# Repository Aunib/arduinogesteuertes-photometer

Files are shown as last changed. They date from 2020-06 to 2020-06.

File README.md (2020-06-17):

# arduinogesteuertes-photometer
Ein arduinogesteuertes Photometer für den Gebrauch an Schulen, entwickelt im Rahmen der Vorbereitung auf meine MSA-Präsentationsprüfung im Schuljahr 2019/20. Die Idee stammt von der Technologiestiftung Berlin.
Textinhalte, Code und Fotos dieses Werkes können genutzt und geteilt werden unter einer Creative Commons NonCommercial-ShareAlike 4.0 International Licensze. (CC BY-NC-SA 4.0)
Als Namensnennung ist anzugeben: Simon Steinberg, 2020.

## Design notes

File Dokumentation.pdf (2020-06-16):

# Bauanleitung für ein „arduinogesteuertes Photometer für den Gebrauch an Schulen“

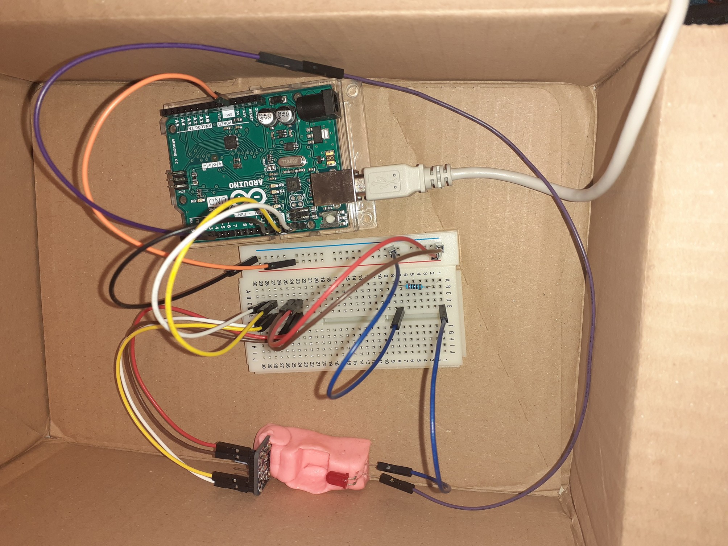
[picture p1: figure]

## Ein MSA-Projekt von Simon Steinberg an der Comenius-Schule Berlin im Auftrag der Technologiestiftung Berlin

## Schuljahr 2019/20

## Inhaltsverzeichnis

## Einkaufsliste

- 1 Arduino UNO
- LED beliebiger Farbe (je nach zu messenden Substanzen, wechselbar)
- 1 Breadboard
- USB-Kabel A auf B
- Lichtsensor: Adafruit TSL 2561
- 8 Jumperkabel male/male
- 6 Jumperkabel male/female
- 1 Widerstand (Stärke hängt von der LED ab, ich verwendete 220 Ω))
- Küvetten zum testen
- Fimo
- Pappkarton o.ä.
- Laptop/stationärer PC mit USB-Anschluss (wird nicht fest verbaut, ist aber zum Programmieren und für die Bedienung nötig)

## Werkzeug

- Backofen
- evtl. Lötkolben (je nach Ausführung des TSL 2561)

## Schaltplan

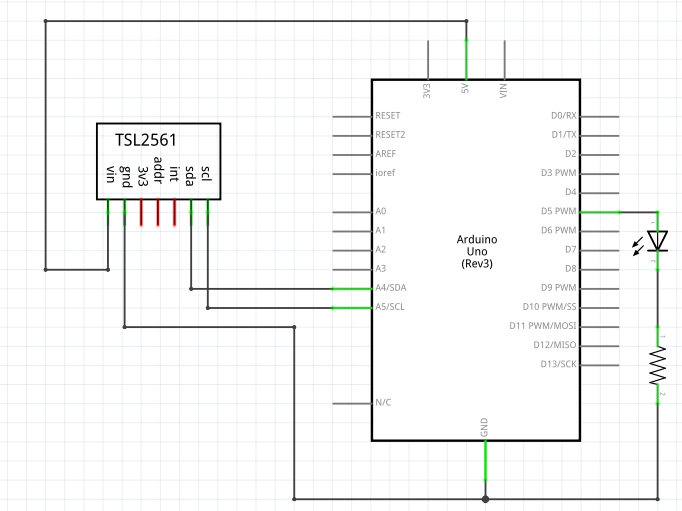
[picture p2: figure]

## Zusammenbau

Der Zusammenbau der Schaltung gestaltet sich relativ einfach:

1. Man nimmt die Bauteile und steckt sie anhand des Schaltplans auf das Breadboard. Dabei ist zu beachten, dass man den Lichtsensor und die LED über male/female Kabel so anschließt, dass man sie im Karton bewegen kann (Damit ist gemeint, dass diese nicht fest auf das Breadboard gesteckt werden. (Siehe Titelbild)).
2. Danach muss man das „Fimo“ in Form bringen
(siehe Bild), welches die Komponenten so
ausrichtet, dass eine Messung möglich wird und gleichzeitig als Halterung für die Messküvette dient.
3. Nachdem man das „Fimo“ geformt hat muss es bei 130 °C für 15 min. in den Ofen.
4. Danach kann man die vorher vorbereiteten Kabel an die LED und den Lichtsensor anschließen.

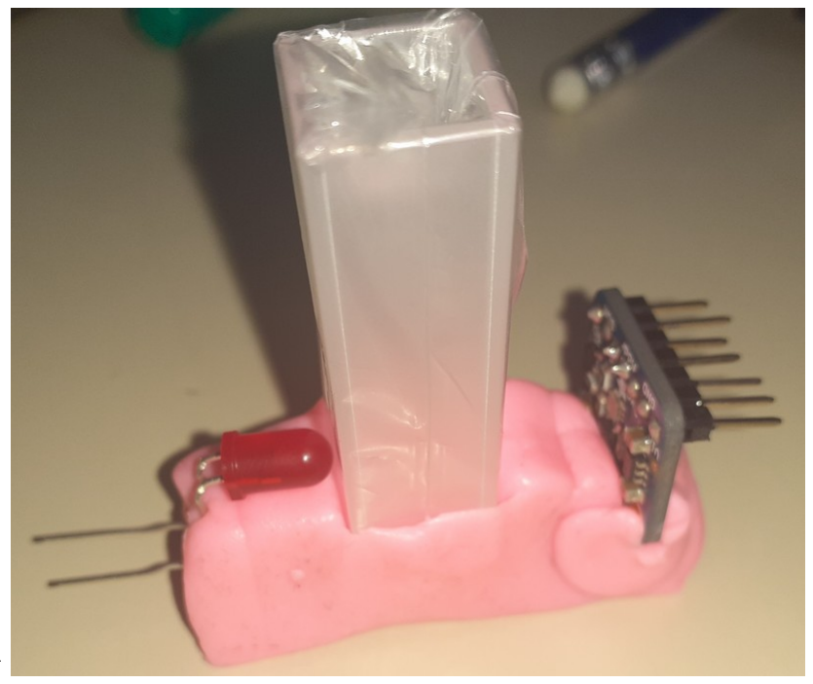
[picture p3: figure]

5. Der USB-Anschluss des Arduino wird nun mit dem USB-Kabel verbunden, dessen anderes Ende im
PC/Laptop steckt.
6. Nun kann man den Arduino mit der korrekten
Software versorgen. Dies wird mit der Arduino-IDE (arduino.cc) erledigt. Dabei benötigt eine nachzuinstallierende Bibliothek namens „Adafruit TSL2561“.
7. Bevor der Code hochgeladen wird, muss man in der Arduino-IDE den seriellen Port einstellen. Dies tut man, indem man auf Werkzeuge => Port geht und dort den Punkt auswählt, hinter dem „(Arduino UNO)“ steht. Dieser Schritt muss jedes mal, wenn man auf den Arduino zugreifen möchte, wiederholt werden. (Also auch vor der Bedienung mit dem seriellen Monitor)
8. Nun kann man den Code laden und auf den Arduino hochladen.
9. Um das Photometer zu bedienen wird der Serielle Monitor (Werkzeuge => Serieller Monitor) genutzt. Die dortige Bedienoberfläche ist relativ selbsterklärend.

Hier sieht man das geformte „Fimo“ mit den Teilen, welche als Formhilfe verwendet werden können.

## Code&Dokumentation

## Software

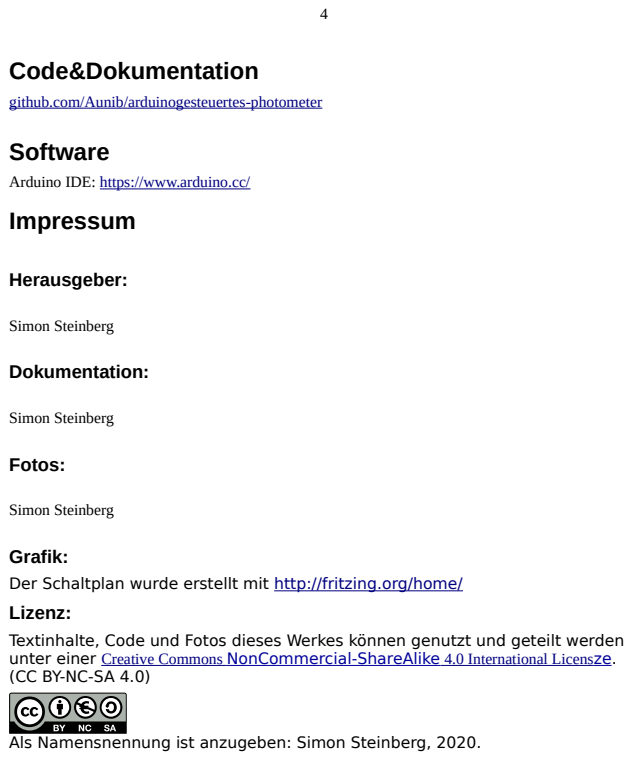
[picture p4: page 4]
Herausgeber:; Simon Steinberg; Dokumentation:; Fotos:

github.com/Aunib/arduinogesteuertes-photometer

Arduino IDE: https://www.arduino.cc/
Impressum

Grafik:
Der Schaltplan wurde erstellt mit http://fritzing.org/home/
Lizenz:
Textinhalte, Code und Fotos dieses Werkes können genutzt und geteilt werden
unter einer Creative Commons (http://creativecommons.org/licenses/by-nc-sa/4.0/) NonCommercial-ShareAlike 4.0 International Licens (http://creativecommons.org/licenses/by-nc-sa/4.0/) z (http://creativecommons.org/licenses/by-nc-sa/4.0/) e. (http://creativecommons.org/licenses/by-nc-sa/4.0/)

Als Namensnennung ist anzugeben: Simon Steinberg, 2020.

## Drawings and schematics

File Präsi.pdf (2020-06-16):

# Arduinogesteuertes Photometer

Entwickelt für den Gebrauch in Schulen

Simon Steinberg

## Inhaltsverzeichnis

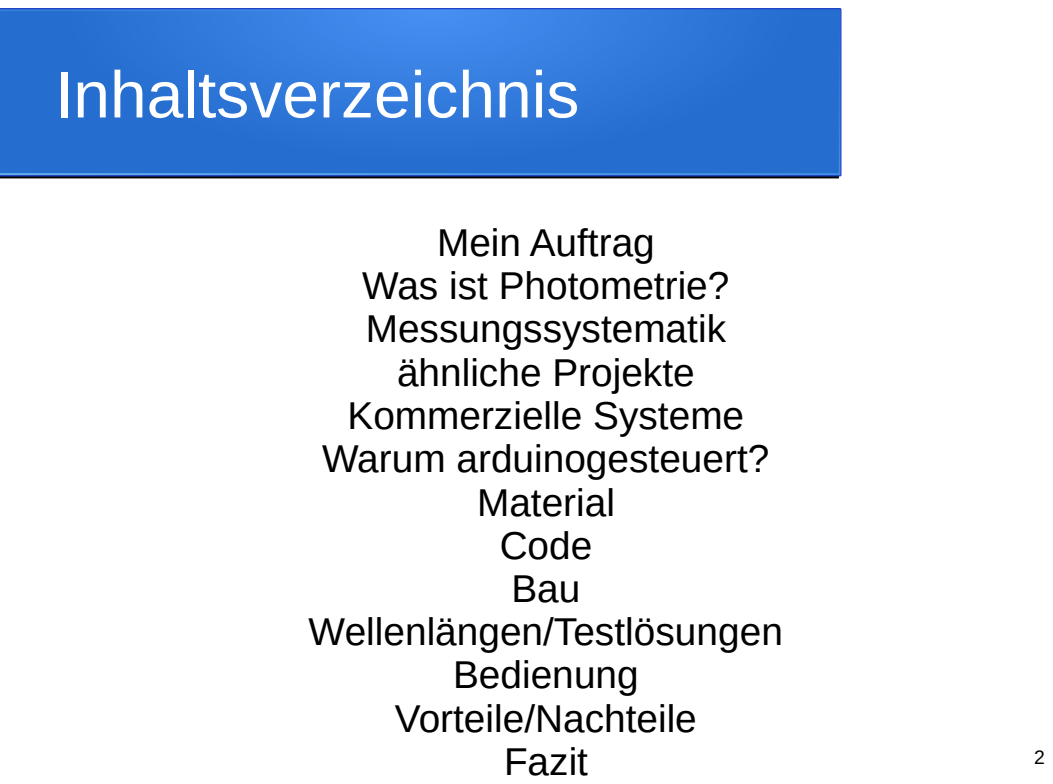
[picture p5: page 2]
Material Code Bau Wellenlängen/Testlösungen Bedienung Vorteile/Nachteile Fazit

Mein Auftrag
Was ist Photometrie?
Messungssystematik
ähnliche Projekte
Kommerzielle Systeme
Warum arduinogesteuert?

## Mein Auftrag

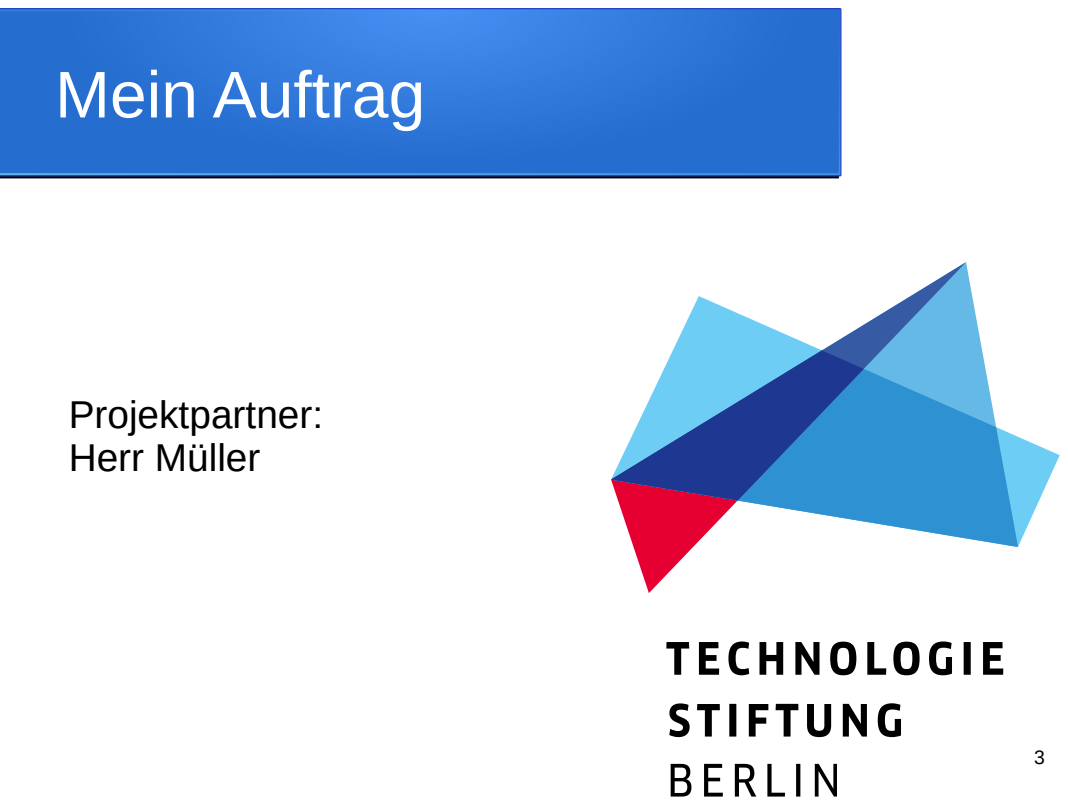
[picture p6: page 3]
Projektpartner: Herr Müller

## Was ist Photometrie?

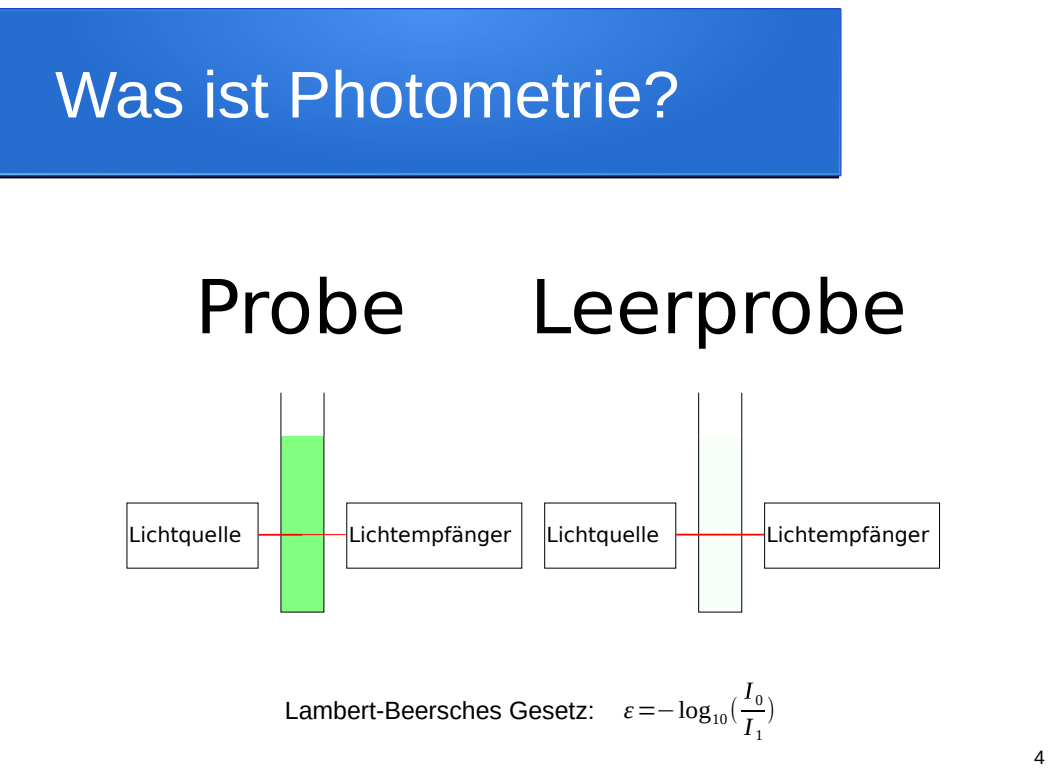
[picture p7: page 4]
Lichtquelle; Lichtempfänger; Probe; Leerprobe

Lambert-Beersches Gesetz: ε=−log10 (

## Messungssystematik

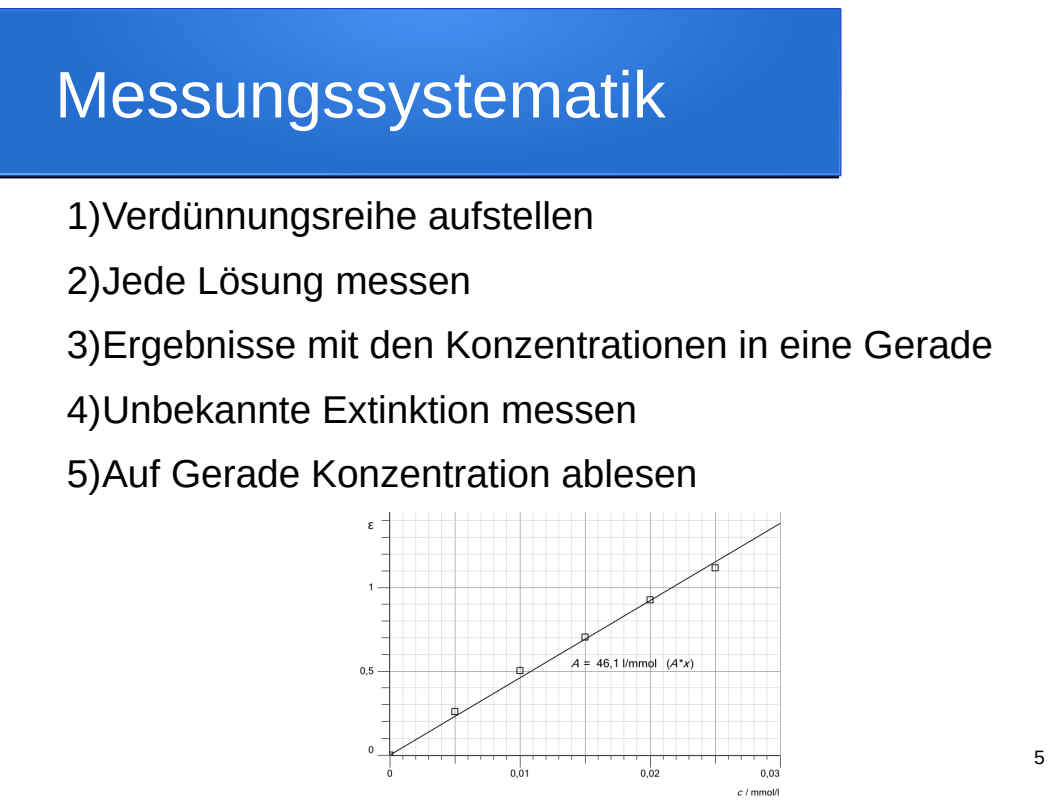
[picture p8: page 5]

1)Verdünnungsreihe aufstellen
2)Jede Lösung messen
3)Ergebnisse mit den Konzentrationen in eine Gerade
4)Unbekannte Extinktion messen
5)Auf Gerade Konzentration ablesen

## Was gibt es noch an Projekten?

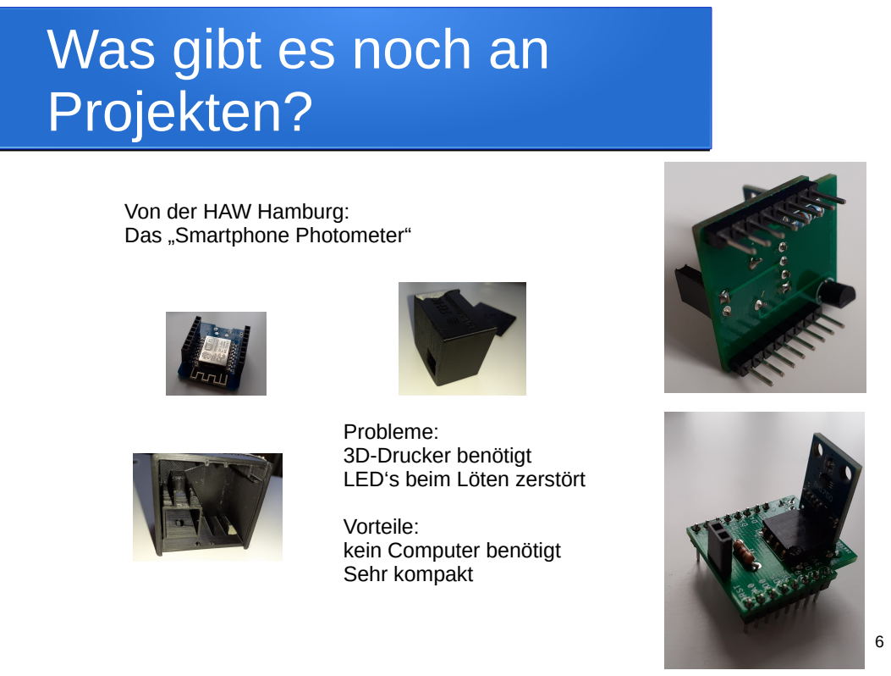
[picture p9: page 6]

Von der HAW Hamburg:
Das „Smartphone Photometer“

Probleme:
3D-Drucker benötigt
LED‘s beim Löten zerstört

Vorteile:
kein Computer benötigt
Sehr kompakt

## Kommerzielle Lösungen

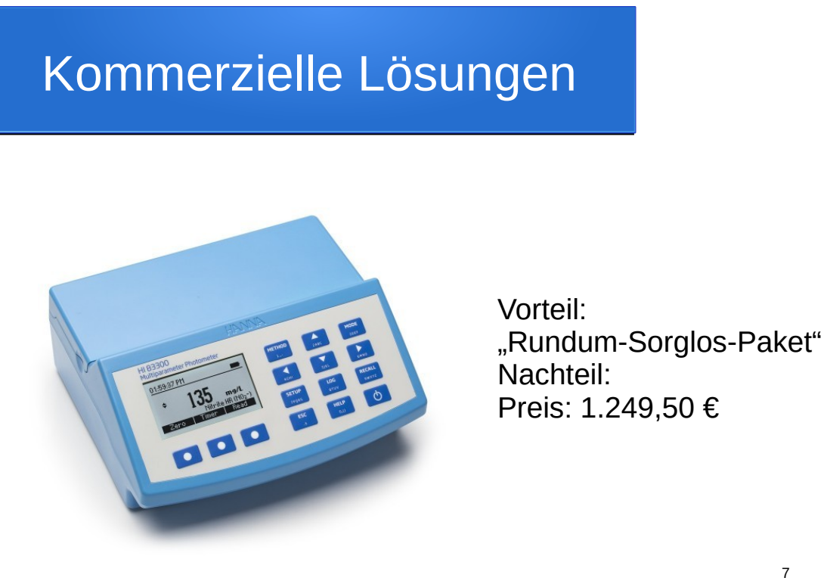
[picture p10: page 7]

Vorteil:
„Rundum-Sorglos-Paket“
Nachteil:
Preis: 1.249,50 €

## Warum Arduinogesteuert?

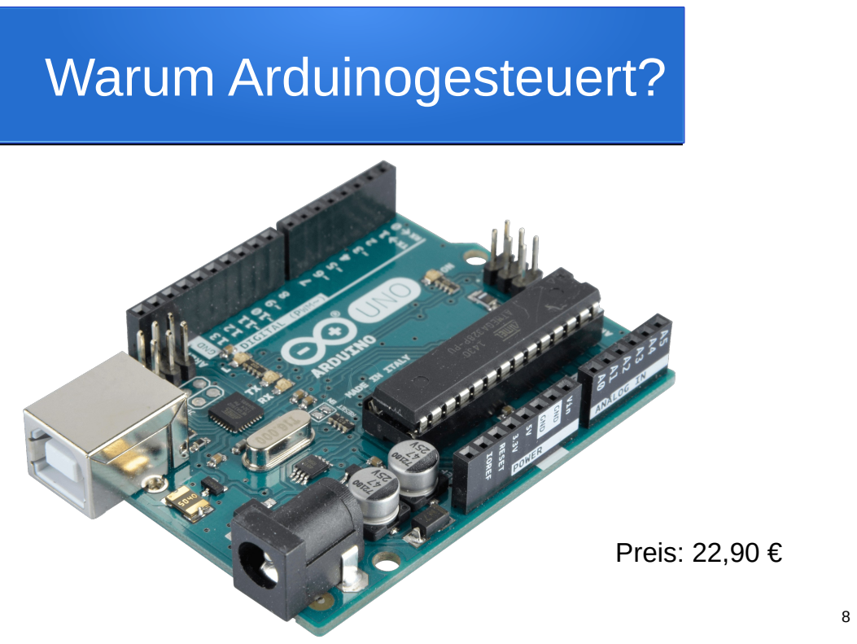
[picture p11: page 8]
Preis: 22,90 €

## Material

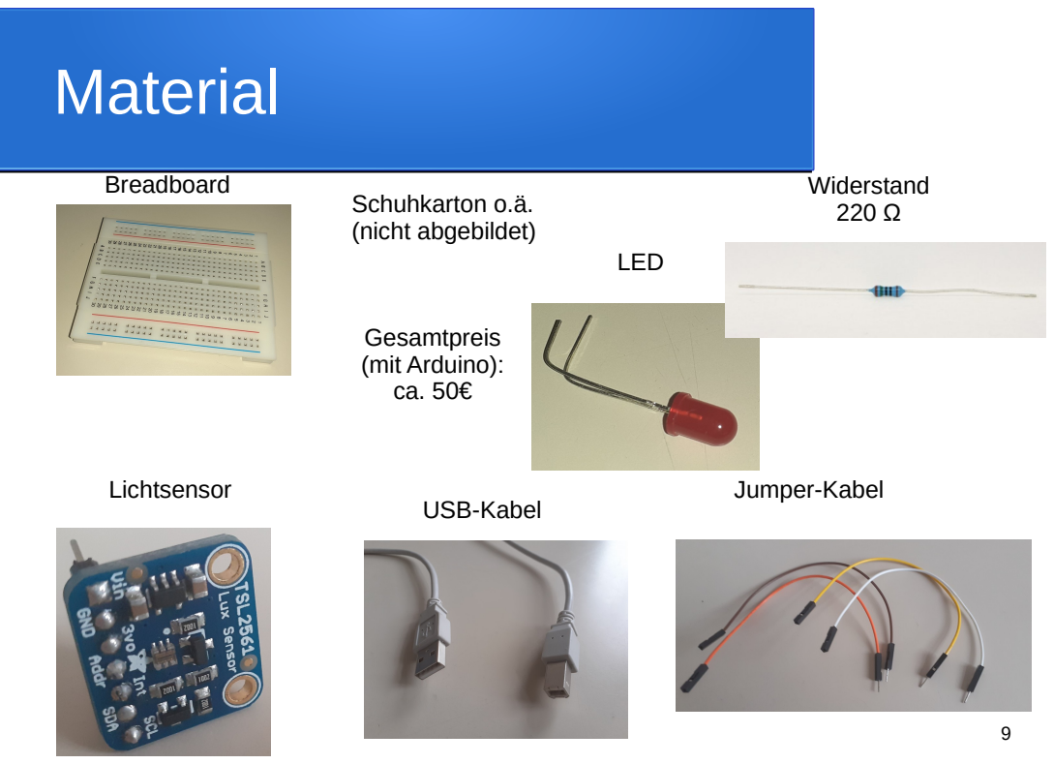
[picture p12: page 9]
Breadboard; LED; Lichtsensor; Jumper-Kabel; USB-Kabel; Gesamtpreis (mit Arduino): ca. 50€; Schuhkarton o.ä. (nicht abgebildet); Widerstand 220 Ω

## Code

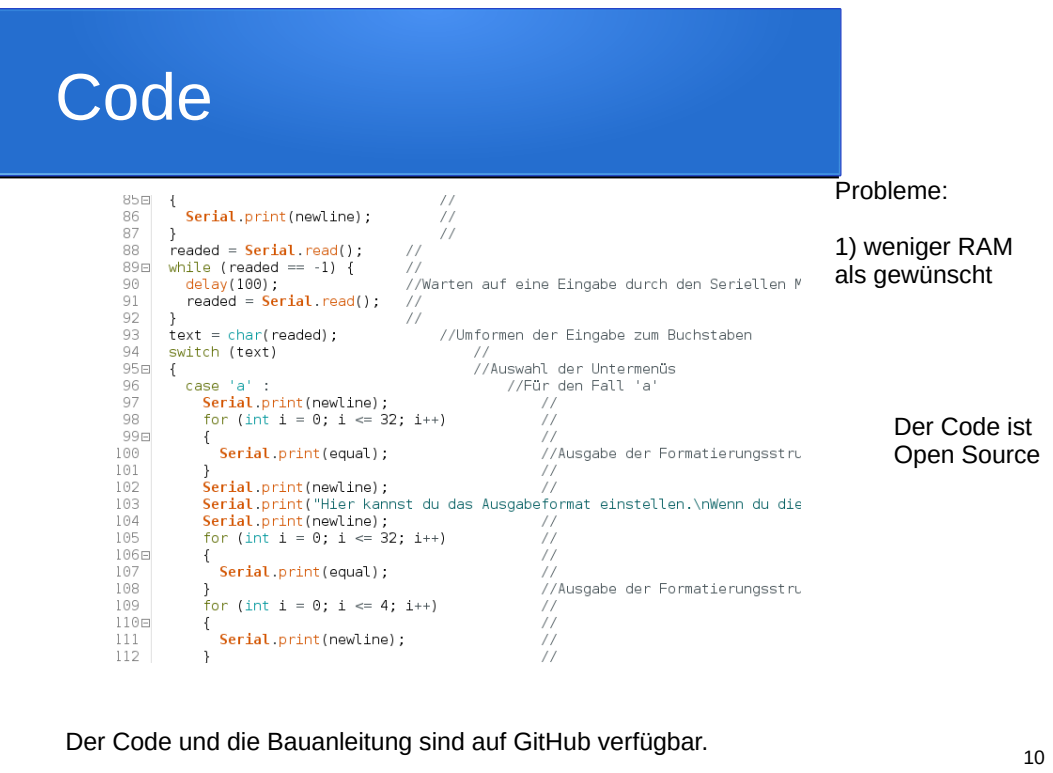
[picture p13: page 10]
Probleme:; 1) weniger RAM als gewünscht

Der Code ist
Open Source

Der Code und die Bauanleitung sind auf GitHub verfügbar.

## Bau

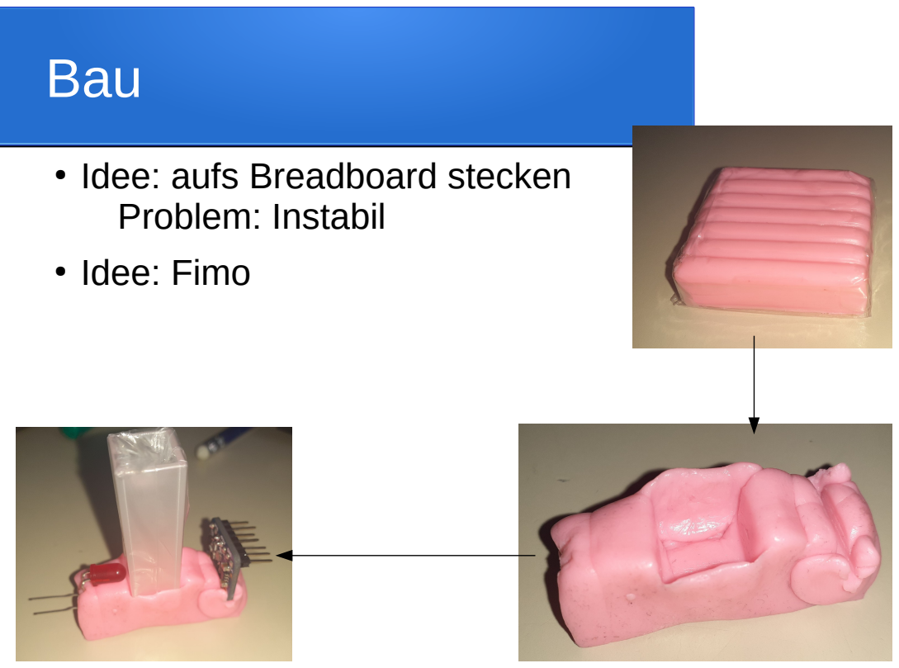
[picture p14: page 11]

● Idee: aufs Breadboard stecken
Problem: Instabil
● Idee: Fimo

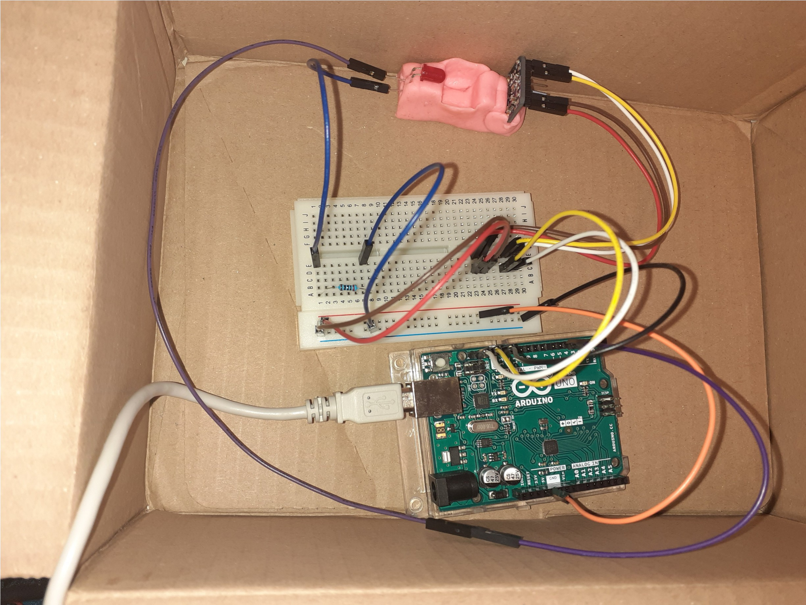
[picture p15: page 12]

## Wellenlängen/ Testlösungen

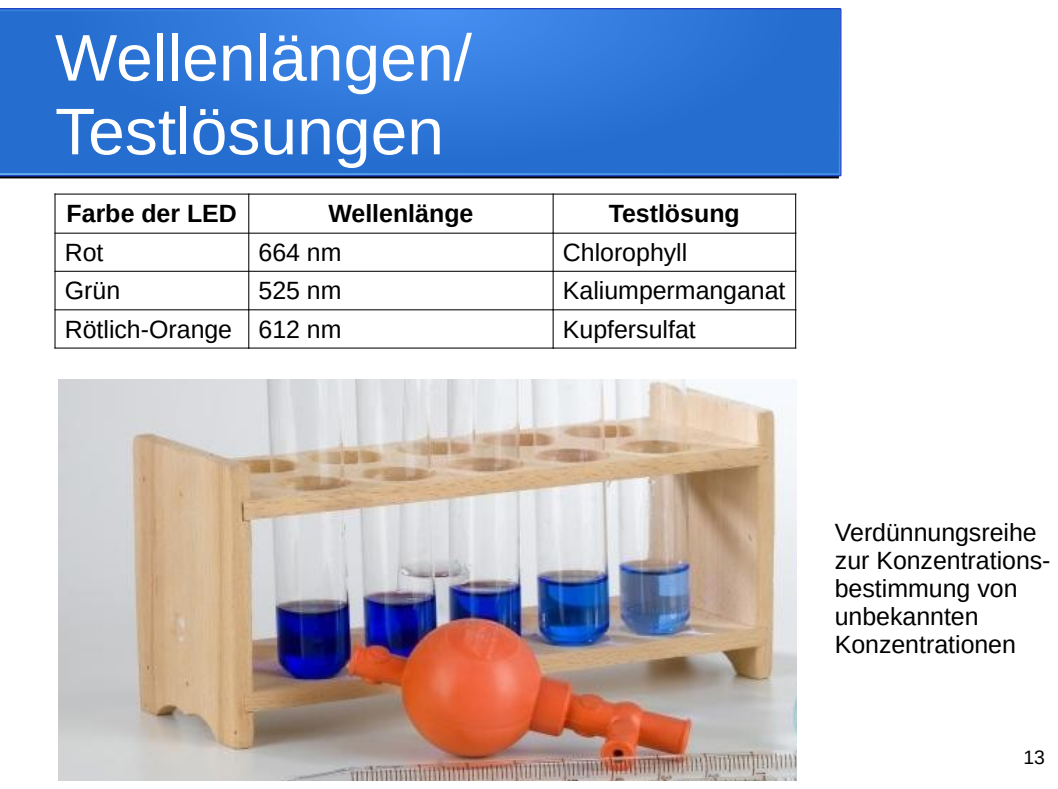
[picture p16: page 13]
Verdünnungsreihe zur Konzentrations- bestimmung von unbekannten Konzentrationen

Farbe der LED | Wellenlänge | Testlösung
Rot | 664 nm | Chlorophyll
Grün | 525 nm | Kaliumpermanganat
Rötlich-Orange | 612 nm | Kupfersulfat

## Bedienung


Mit dem seriellen Monitor

## Vorteile/Nachteile meiner Lösung

Vorteile; Nachteile

● mehrere zeitgleiche Experimente
möglich
● Erfahrungen in
IT/Elektronik beim Bau
● relativ preisgünstig

● Pro Photometer ein Laptop oder
PC benötigt
● verschiedene Zwischenergebnisse
bei verschiedenen Aufbauten?

## Fazit


● Auftrag von Herr Müller erfüllt
● Code geschrieben
● Prototyp entwickelt
● An Schulen einsetzbar

# Danke für Ihre Aufmerksamkeit

## Quellen


● https://hannainst.de/media/image/48/a6/b8/
hi83300_600x600.jpg (https://hannainst.de/media/image/48/a6/b8/hi83300_600x600.jpg)
● https://cdn-reichelt.de/bilder/web/xxl_ws/A3
00/ARDUINO_UNO_DIP_01.png (https://cdn-reichelt.de/bilder/web/xxl_ws/A300/ARDUINO_UNO_DIP_01.png)
● https://www.technologiestiftung-berlin.de/typ
o3conf/ext/ccdm_tsbtemplate/Resources/Pu
blic/Bootstrap/img/tsb-logo-content.svg (https://www.technologiestiftung-berlin.de/typo3conf/ext/ccdm_tsbtemplate/Resources/Public/Bootstrap/img/tsb-logo-content.svg)
● https://www.elriwa.de/media/image/b9/0f/0b/
166394_widerstand_600x600.jpg (https://www.elriwa.de/media/image/b9/0f/0b/166394_widerstand_600x600.jpg)

## Quellen


● https://riecken.de/index.php/2010/01/chemi
e-fotometrie-mit-kaliumpermanganatlosung/ (https://riecken.de/index.php/2010/01/chemie-fotometrie-mit-kaliumpermanganatlosung/)
● https://www.hug-technik.com/inhalt/ta/farbe
n.html (https://www.hug-technik.com/inhalt/ta/farben.html)
● http://www.physik.uni-regensburg.de/studiu
m/praktika/pharma/download/Versuch9.pdf (http://www.physik.uni-regensburg.de/studium/praktika/pharma/download/Versuch9.pdf)
● https://www.ld-didactic.de/documents/en-US
/EXP/C/C3/C3321_d.pdf (https://www.ld-didactic.de/documents/en-US/EXP/C/C3/C3321_d.pdf)

## Impressum

Herausgeber:; Simon Steinberg

Grafik:
Der Schaltplan wurde erstellt mit http://fritzing.org/home/
Lizenz:
Textinhalte, Code und Fotos dieses Werkes können genutzt und geteilt werden unter einer
Creative Commons (http://creativecommons.org/licenses/by-nc-sa/4.0/) NonCommercial-ShareAlike 4.0 International Licens (http://creativecommons.org/licenses/by-nc-sa/4.0/)z (http://creativecommons.org/licenses/by-nc-sa/4.0/)e. (http://creativecommons.org/licenses/by-nc-sa/4.0/) (CC BY-NC-SA 4.0)
Als Namensnennung ist anzugeben: Simon Steinberg, 2020.

GitHub-Repo:
github.com/Aunib/arduinogesteuertes-photometer/

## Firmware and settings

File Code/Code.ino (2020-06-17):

/*
   Der Beispielcode wurde von Adafruit übernommen

   Dieser Code wurde von Simon Steinberg im Rahmen der vorbereitung auf die MSA-Präsentationsprüfung im Schuljahr 2019/2020 erstellt.


   Dieses Werk kann genutzt und geteilt werden unter einer Creative Commons NonCommercial-ShareAlike 4.0 International Licensze. (CC BY-NC-SA 4.0)
   Als Namensnennung ist anzugeben: Simon Steinberg, 2020.
*/


/*
   Bibliothek für ...
*/

#include <Wire.h>                 //Serielle Kommunikation
#include <Adafruit_Sensor.h>      //Sensoren von Adafruit
#include <Adafruit_TSL2561_U.h>   //Lichtsensor TSL_2561_U von Adafruit
#include <math.h>                 //Mathematische berechnungen


/*
   Variablendefinitionen:
*/
int readed;             //Aktuelle Eingabe aus dem Seriellen Monitor
char text;              //readed als Buchstabe
int ausgabeformat;      //Aktuelle Einstellung des Ausgabeformates: 0=lux, 1=Extinktion
int lux;                //Aktueller Messwert
int leer;               //Wert der Leerprobe
#define messung_led 5   //Pin, an den die LED angeschlossen ist

Adafruit_TSL2561_Unified tsl = Adafruit_TSL2561_Unified(TSL2561_ADDR_FLOAT, 12345); //Initialisierung des Lichtsensors

void displaySensorDetails(void) //Aus dem Beispielcode übernommene Funktion um Sensoreinstellungen anzuzeigen
{
  sensor_t sensor;
  tsl.getSensor(&sensor);
  Serial.println("------------------------------------");
  Serial.print  ("Sensor:       "); Serial.println(sensor.name);
  Serial.print  ("Driver Ver:   "); Serial.println(sensor.version);
  Serial.print  ("Unique ID:    "); Serial.println(sensor.sensor_id);
  Serial.print  ("Max Value:    "); Serial.print(sensor.max_value); Serial.println(" lux");
  Serial.print  ("Min Value:    "); Serial.print(sensor.min_value); Serial.println(" lux");
  Serial.print  ("Resolution:   "); Serial.print(sensor.resolution); Serial.println(" lux");
  Serial.println("------------------------------------");
  Serial.println("");
  delay(500);
}

/**************************************************************************/
/*
    Configures the gain and integration time for the TSL2561
*/
/**************************************************************************/
void configureSensor(void)    //Aus dem Beispielcode übernommene Funktion um den Sensor zu konfigurieren
{
  tsl.enableAutoRange(true);            /* Auto-gain ... switches automatically between 1x and 16x */

  /* Changing the integration time gives you better sensor resolution (402ms = 16-bit data) */
  tsl.setIntegrationTime(TSL2561_INTEGRATIONTIME_13MS);      /* fast but low resolution */

  /* Update these values depending on what you've set above! */
  Serial.println("------------------------------------");
  Serial.print  ("Gain:         "); Serial.println("Auto");
  Serial.print  ("Timing:       "); Serial.println("13 ms");
  Serial.println("------------------------------------");
}

void menue()    //Von mir geschriebene Funktion, um den Sensor mithilfe des Seriellen Monitors anzusteuern
{
  char equal = '\=';              //Definition zweier Variablen, um die Menügestaltung zu realisieren(Wenn ich diese Texte jeweils in die Strings schreiben würde, würde der RAM vollaufen.
  char newline = '\n';            //
  readed = Serial.read();     //Auslesen des Inputs aus dem seriellen Monitor
  Serial.print(newline);          //
  for (int i = 0; i <= 32; i++)   //
  { //Ausgabe der Formatierungsstruktur für den Seriellen Monitor
    Serial.print(equal);          //
  }                               //
  Serial.print(newline);          //
  Serial.print("Herzlich Willkommen im Hauptmenue des Arduinogesteuerten Photometers.\nBitte gib \"a\" ein und bestätige, um das Ausgabeformat einzustellen.\nBitte gib \"m\" ein und bestätige, um eine Messung durchzuführen.");//Ausgabe des Hauptmenüs
  Serial.print(newline);          //
  for (int i = 0; i <= 32; i++)   //
  { //
    Serial.print(equal);          //
  }                               //
  for (int i = 0; i <= 4; i++)    //Ausgabe der Formatierungsstruktur für den Seriellen Monitor
  { //
    Serial.print(newline);        //
  }                               //
  readed = Serial.read();     //
  while (readed == -1) {      //
    delay(100);               //Warten auf eine Eingabe durch den Seriellen Monitor
    readed = Serial.read();   //
  }                           //
  text = char(readed);            //Umformen der Eingabe zum Buchstaben
  switch (text)                       //
  { //Auswahl der Untermenüs
    case 'a' :                            //Für den Fall 'a'
      Serial.print(newline);                  //
      for (int i = 0; i <= 32; i++)           //
      { //
        Serial.print(equal);                  //Ausgabe der Formatierungsstruktur für den Seriellen Monitor
      }                                       //
      Serial.print(newline);                  //
      Serial.print("Hier kannst du das Ausgabeformat einstellen.\nWenn du die Ausgabe in Form von LUX haben möchtest, gib bitte \"l\" ein und bestätige.\nWenn du die Ausgabe in Form eines Extinktionswertes haben möchtest, gib bitte \"e\" ein und bestätige.");   //Ausgabe des Menüs für die Ausgabeart
      Serial.print(newline);                  //
      for (int i = 0; i <= 32; i++)           //
      { //
        Serial.print(equal);                  //
      }                                       //Ausgabe der Formatierungsstruktur für den Seriellen Monitor
      for (int i = 0; i <= 4; i++)            //
      { //
        Serial.print(newline);                //
      }                                       //
      readed = Serial.read();             //
      do {                                //
        delay(100);                       //Warten auf eine Eingabe durch den Seriellen Monitor
        readed = Serial.read();           //
      } while (readed == -1);             //
      text = char(readed);            //Umformen der Eingabe zum Buchstaben
      switch (text)                       //
      { //Auswahl der Untermenüs
        case 'l' :                            //Für den Fall 'l'
          ausgabeformat = 0;               //Setze die Variable 'ausgabeformat' auf "0"
          Serial.print(newline);              //
          for (int i = 0; i <= 32; i++)       //
          { //
            Serial.print(equal);              //Ausgabe der Formatierungsstruktur für den Seriellen Monitor
          }                                   //
          Serial.print(newline);              //
          Serial.print("0");
          Serial.print("Das Ausgabeformat wurde Erfolgreich auf \"LUX\" eingestellt.");   //Ausgabe der Bestätigungsnachricht auf den Seriellen Monitor
          Serial.print(newline);              //
          for (int i = 0; i <= 32; i++)       //
          { //
            Serial.print(equal);              //
          }                                   //Ausgabe der Formatierungsstruktur für den Seriellen Monitor
          for (int i = 0; i <= 4; i++)        //
          { //
            Serial.print(newline);            //
          }                                   //
          break;                          //Beendigung des Falls 'l'
        case 'e' :                            //Für den Fall 'e':
          ausgabeformat = 1;              //Setze die Variable 'ausgabeformat' auf "1"
          Serial.print(newline);              //
          for (int i = 0; i <= 32; i++)       //
          { //
            Serial.print(equal);              //Ausgabe der Formatierungsstruktur für den Seriellen Monitor
          }                                   //
          Serial.print(newline);              //
          Serial.print("1");
          Serial.print("Das Ausgabeformat wurde Erfolgreich auf \"Extinktionsswert\" eingestellt.");   //Ausgabe der Bestätigungsnachricht auf den Seriellen Monitor
          Serial.print(newline);              //
          for (int i = 0; i <= 32; i++)       //
          { //
            Serial.print(equal);              //
          }                                   //
          for (int i = 0; i <= 4; i++)        //Ausgabe der Formatierungsstruktur für den Seriellen Monitor
          { //
            Serial.print(newline);            //
          }                                   //
          break;                          //Beendigung des Falls 'e'

      }
      break;                          //Beendigung des Falls 'l'
    case 'm' :                            //Für den Fall 'm'
      Serial.print(newline);          //
      for (int i = 0; i <= 32; i++)   //
      { //Ausgabe der Formatierungsstruktur für den Seriellen Monitor
        Serial.print(equal);          //
      }                               //
      Serial.print(newline);          //
      Serial.print("Wenn du eine Leerprobe durchführen und das Ergebnis speichern möchtest, gebe bitte \"l\" ein und bestätige.\nWenn du eine Messung durchführen möchtest, gebe bitte \"m\" ein und bestätige.");//Ausgabe des Messungsmenüs über den Seriellen Monitor
      Serial.print(newline);          //
      for (int i = 0; i <= 32; i++)   //
      { //
        Serial.print(equal);          //
      }                               //
      for (int i = 0; i <= 4; i++)    //Ausgabe der Formatierungsstruktur für den Seriellen Monitor
      { //
        Serial.print(newline);        //
      }                               //
      readed = Serial.read();     //
      do {                        //
        delay(100);               //Warten auf eingabe durch den Seriellen Monitor
        readed = Serial.read();   //
      } while (readed == -1);     //
      switch (readed)                 //Auswahl für Funktionen
      { //
        case 'l':                         //Falls 'l' :
          lux = messung();            //Durchführung der Messung
          Serial.print(newline);          //
          for (int i = 0; i <= 32; i++)   //
          { //
            Serial.print(equal);          //Ausgabe der Formatierungsstruktur über den Seriellen Monitor
          }                               //
          Serial.print(newline);          //
          Serial.print("Das Ergebnis der Leerprobe ist ");//Ausgabe des Rahmens über den Seriellen Monitor
          Serial.print(lux);              //Ausgabe des Messwertes
          leer = lux;                         //Speicherung des Messwertes in der Variable "leer"
          Serial.print(" LUX.\nDieser Wert wurde erfolgreich als Wert der Leerprobe abgespeichert.");//Ausgabe über den Seriellen Monitor
          Serial.print(newline);          //
          for (int i = 0; i <= 32; i++)   //
          { //
            Serial.print(equal);          //
          }                               //
          for (int i = 0; i <= 4; i++)    //Ausgabe der Formatierungsstruktur über den Seriellen Monitor
          { //
            Serial.print(newline);        //
          }                               //
          break;                      //Beendigung des Falls 'l'
        case 'm':                         //Falls 'm'
          lux = messung();                    //Durchführung der Messung
          Serial.print(newline);          //
          for (int i = 0; i <= 32; i++)   //
          { //
            Serial.print(equal);          //Ausgabe der Formatierungsstruktur über den Seriellen Monitor
          }                               //
          Serial.print(newline);          //
          Serial.print("Das Ergebnis der Probe ist ");//Ausgabe des Rahmens über den Seriellen Monitor
          switch (ausgabeformat) {            //Auswahl für Ausgabeformate
            case 0:                             //falls '0' (LUX)
              Serial.print(lux);              //Ausgabe des Messwertes
              Serial.print("LUX.");               //Ausgabe über den Seriellen Monitor
              break;                          //
            case 1:                     //falls '1' (Extinktion)
              Serial.print(berechneExtinktion(lux, leer));
              break;
              for (int i = 0; i <= 32; i++)   //
              { //
                Serial.print(equal);          //
              }                               //
              for (int i = 0; i <= 4; i++)    //Ausgabe der Formatierungsstruktur über den Seriellen Monitor
              { //
                Serial.print(newline);        //
              }                               //
          }
          break;                      //Beendigung des Falls 'm'
      }
  }
}

float berechneExtinktion(int I0, int I1)//selbstgeschriebene Funktion, um die Extinktion zu berechnen.
{
  return (I0 / I1);//Eigendliche Berechnung
}

int messung() {                     //selbstgeschriebene Funktion, um die Messung durchzuführen
  int ergebnis;                         //neuer Integer, um das Ergebnis zwischenzuspeichern
  digitalWrite(messung_led, HIGH);  //LED anschalten
  delay(250);                           //250 ms warten
  sensors_event_t event;            //
  tsl.getEvent(&event);             //
  if (event.light)                  //
  { //aus dem Beispielcode übernommene Codezeilen, um jetzt wirklich zu messen.
    ergebnis = (event.light);       //
  }                                 //
  delay(250);                           //250 ms warten
  digitalWrite(messung_led, LOW);   //LED ausschalten
  return (ergebnis);            //Funktion beenden und den Inhalt von 'ergebnis' zurückgeben
}

void setup(void)                    //Setup-Funktion des Arduinos
{
  Serial.begin(9600);                   //Beginn der Seriellen Kommunikation mit dem Seriellen Monitor (Geschwindigkeit 9600 Baud)
  Serial.println("Light Sensor Test"); Serial.println("");                          //
  //
  if (!tsl.begin())                                                                 //
  { //
    /* There was a problem detecting the TSL2561 ... check your connections */      //
    Serial.print("Ooops, no TSL2561 detected ... Check your wiring or I2C ADDR!");  //
    while (1);                                                                      //
  }                                                                                 //Aus dem Beispielcode übernommen
  //
  /* Display some basic information on this sensor */                               //
  displaySensorDetails();                                                           //
  //
  /* Setup the sensor gain and integration time */                                  //
  configureSensor();                                                                //
  //
  /* We're ready to go! */                                                          //
  Serial.println("");                                                               //
  //
  pinMode(messung_led, OUTPUT);                                                 //Den LED-Pin auf Ausgang stellen
}

void loop(void)                   //Wiederholt sich immer
{
  menue();                    //Aufrufen der Menü-funktion
  delay(250);                     //250 ms warten
}
